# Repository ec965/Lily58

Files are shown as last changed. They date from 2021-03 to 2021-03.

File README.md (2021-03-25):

# SMD Lily58
* ATMEGA32U4 and STM32F072 variants
* Full SMD MCU and components.
* Original parts kept true to original placement where ever possible.
* Reversible PCB to reduce costs.
* USB C port on the left side.
* MCP23017 IO expander to reduce cost over two MCUs.

# Lily58
Lily58 is 6*4+4keys column-staggered split keyboard.
Lily58Lite-Pic

## [Document Site Here](https://kata0510.github.io/Lily58-Document/)

# Type

- Lily58 Pro
  - [PCB Data](https://github.com/kata0510/Lily58/tree/master/Pro/PCB)
  - [BuildGuide JP](https://kata0510.github.io/Lily58-Document/Lily58_Pro.html)
  - [BuildGuide EN](https://kata0510.github.io/Lily58-Document/Lily58_Pro_BG_ENG.html)
  - [Shop(Yushakobo)](https://yushakobo.jp/shop/lily58-pro/)
- Lily58 Lite Rev2
  - [BuildGuide(YouTube)](https://www.youtube.com/watch?v=t6HLQvqlsVM)
  - [BuildInfo](https://kata0510.github.io/Lily58-Document/Lily58_Lite_Rev2.html)
  - [Shop(BOOTH)](https://booth.pm/ja/items/1963895)
  - [Shop(Yushakobo)](https://yushakobo.jp/shop/consign_lily58-lite-rev2/)
- Lily58(Old)
  - [PCB Data](https://github.com/kata0510/Lily58/tree/master/pcb)
  - [BuildGuide](https://kata0510.github.io/Lily58-Document/Lily58_BG.html)
- Lily58 Lite Rev1(Old)
  - [PCB Data](https://github.com/kata0510/Lily58/tree/master/pcb)
  - [BuildGuide](https://kata0510.github.io/Lily58-Document/Lily58_Lite_BG.html)

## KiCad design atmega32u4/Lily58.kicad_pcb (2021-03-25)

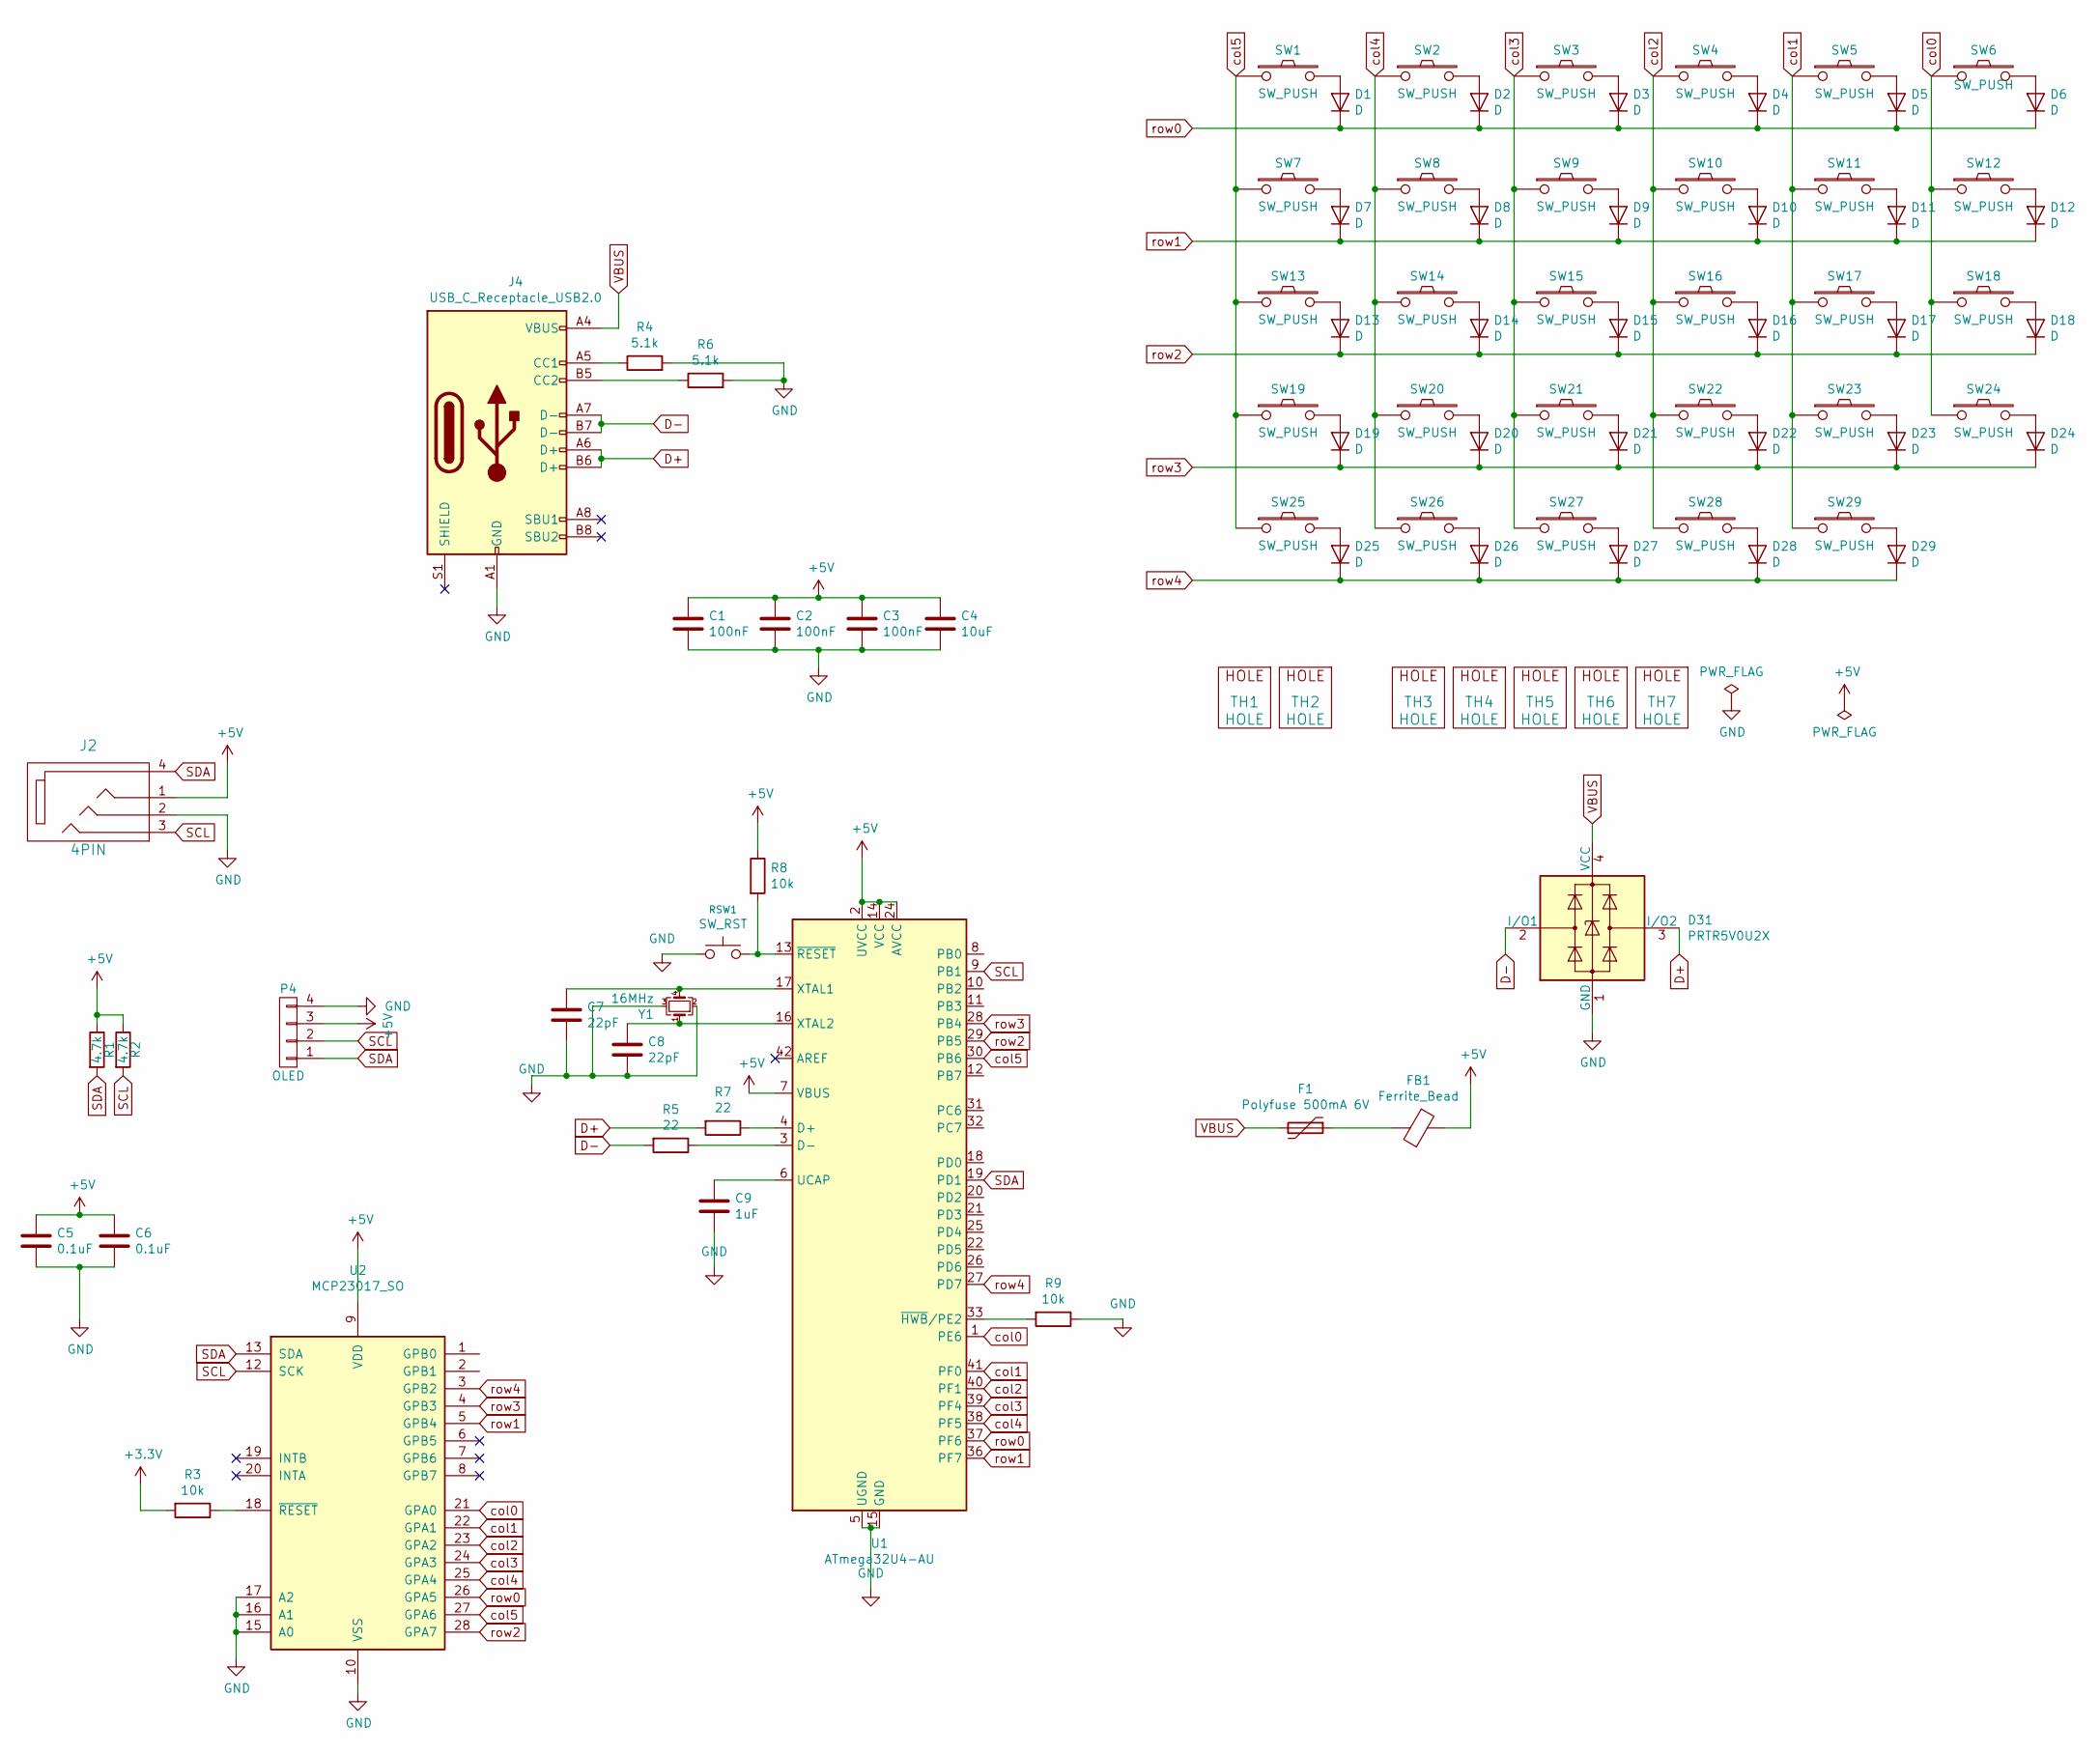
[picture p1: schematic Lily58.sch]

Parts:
C1, C2, C3: 100nF; C_0805_2012Metric
C4: 10uF; C_0805_2012Metric
C5, C6: 0.1uF; C_0805_2012Metric
C7, C8: 22pF; C_0805_2012Metric
C9: 1uF; C_0805_2012Metric
D1, D2, D3, D4, D5, D6, D7, D8, D9, D10, D11, D12, D13, D14, D15, D16, D17, D18, D19, D20, D21, D22, D23, D24, D25, D26, D27, D28, D29: D; Diode_TH_SOD123
D31: PRTR5V0U2X; SOT-143
F1: Polyfuse 500mA 6V; R_0805_2012Metric
FB1: Ferrite_Bead; L_0805_2012Metric
J2: 4PIN; MJ-4PP-9
J4: USB_C_Receptacle_USB2.0; USB_C_Receptacle_Palconn_UTC16-G
P4: OLED; MY_SIL-4
R1, R2: 4.7k; R_0805_2012Metric
R3, R8, R9: 10k; R_0805_2012Metric
R4, R6: 5.1k; R_0805_2012Metric
R5, R7: 22; R_0805_2012Metric
RSW1: SW_RST; TACT_SWITCH_TVBP06
SW1, SW2, SW3, SW4, SW5, SW6, SW7, SW8, SW9, SW10, SW11, SW12, SW13, SW14, SW15, SW16, SW17, SW18, SW19, SW20, SW21, SW22, SW23, SW24, SW25, SW27, SW28, SW29: SW_PUSH; MX_PG1350-Under_FLIP_HOLES_18mm
SW26: SW_PUSH; MX_PG1350-Under_FLIP_HOLES_27mm
TH1, TH2: HOLE; HOLE_M2
TH3, TH4, TH5, TH6, TH7: HOLE; HOLE_M2_TH
U1: ATmega32U4-AU; TQFP-44_10x10mm_P0.8mm
U2: MCP23017_SO; SOIC-28W_7.5x17.9mm_P1.27mm
Y1: 16MHz; Crystal_SMD_3225-4Pin_3.2x2.5mm

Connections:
D+: D31.3 (I/O2), J4.A6 (D+), J4.B6 (D+), R7.2
D-: D31.2 (I/O1), J4.A7 (D-), J4.B7 (D-), R5.2
GND: C1.2, C2.2, C3.2, C4.2, C5.2, C6.2, C7.2, C8.1, C9.2, D31.1 (GND), J2.2, J4.A1 (GND), J4.A12 (GND), J4.B1 (GND), J4.B12 (GND), P4.4, R4.2, R6.2, R9.1, RSW1.1, U1.5 (UGND), U1.15 (GND), U1.23 (GND), U1.35 (GND), U1.43 (GND), U2.10 (VSS), U2.15 (A0), U2.16 (A1), U2.17 (A2), Y1.2, Y1.3
unnamed: C7.1, U1.17 (XTAL1), Y1.4
unnamed: C8.2, U1.16 (XTAL2), Y1.1
unnamed: C9.1, U1.6 (UCAP)
unnamed: D1.2 (A), SW1.2
unnamed: D2.2 (A), SW2.2
unnamed: D3.2 (A), SW3.2
unnamed: D4.2 (A), SW4.2
unnamed: D5.2 (A), SW5.2
unnamed: D6.2 (A), SW6.2
unnamed: D7.2 (A), SW7.2
unnamed: D8.2 (A), SW8.2
unnamed: D9.2 (A), SW9.2
unnamed: D10.2 (A), SW10.2
unnamed: D11.2 (A), SW11.2
unnamed: D12.2 (A), SW12.2
unnamed: D13.2 (A), SW13.2
unnamed: D14.2 (A), SW14.2
unnamed: D15.2 (A), SW15.2
unnamed: D16.2 (A), SW16.2
unnamed: D17.2 (A), SW17.2
unnamed: D18.2 (A), SW18.2
unnamed: D19.2 (A), SW19.2
unnamed: D20.2 (A), SW20.2
unnamed: D21.2 (A), SW21.2
unnamed: D22.2 (A), SW22.2
unnamed: D23.2 (A), SW23.2
unnamed: D24.2 (A), SW24.2
unnamed: D25.2 (A), SW25.2
unnamed: D26.2 (A), SW26.2
unnamed: D27.2 (A), SW27.2
unnamed: D28.2 (A), SW28.2
unnamed: D29.2 (A), SW29.2
unnamed: F1.1, FB1.2
unnamed: J4.A5 (CC1), R4.1
unnamed: J4.B5 (CC2), R6.1
unnamed: R3.1, U2.18 (~RESET~)
unnamed: R5.1, U1.3 (D-)
unnamed: R7.1, U1.4 (D+)
unnamed: R8.2, RSW1.2, U1.13 (~RESET)
unnamed: R9.2, U1.33 (~HWB~/PE2)
SCL: J2.3, P4.2, R2.2, U1.9 (PB1), U2.12 (SCK)
SDA: J2.4, P4.1, R1.2, U1.19 (PD1), U2.13 (SDA)
VBUS: D31.4 (VCC), F1.2, J4.A4 (VBUS), J4.A9 (VBUS), J4.B4 (VBUS), J4.B9 (VBUS)
col0: SW6.1, SW12.1, SW18.1, SW24.1, U1.1 (PE6), U2.21 (GPA0)
col1: SW5.1, SW11.1, SW17.1, SW23.1, SW29.1, U1.41 (PF0), U2.22 (GPA1)
col2: SW4.1, SW10.1, SW16.1, SW22.1, SW28.1, U1.40 (PF1), U2.23 (GPA2)
col3: SW3.1, SW9.1, SW15.1, SW21.1, SW27.1, U1.39 (PF4), U2.24 (GPA3)
col4: SW2.1, SW8.1, SW14.1, SW20.1, SW26.1, U1.38 (PF5), U2.25 (GPA4)
col5: SW1.1, SW7.1, SW13.1, SW19.1, SW25.1, U1.30 (PB6), U2.27 (GPA6)
row0: D1.1 (K), D2.1 (K), D3.1 (K), D4.1 (K), D5.1 (K), D6.1 (K), U1.37 (PF6), U2.26 (GPA5)
row1: D7.1 (K), D8.1 (K), D9.1 (K), D10.1 (K), D11.1 (K), D12.1 (K), U1.36 (PF7), U2.5 (GPB4)
row2: D13.1 (K), D14.1 (K), D15.1 (K), D16.1 (K), D17.1 (K), D18.1 (K), U1.29 (PB5), U2.28 (GPA7)
row3: D19.1 (K), D20.1 (K), D21.1 (K), D22.1 (K), D23.1 (K), D24.1 (K), U1.28 (PB4), U2.4 (GPB3)
row4: D25.1 (K), D26.1 (K), D27.1 (K), D28.1 (K), D29.1 (K), U1.27 (PD7), U2.3 (GPB2)

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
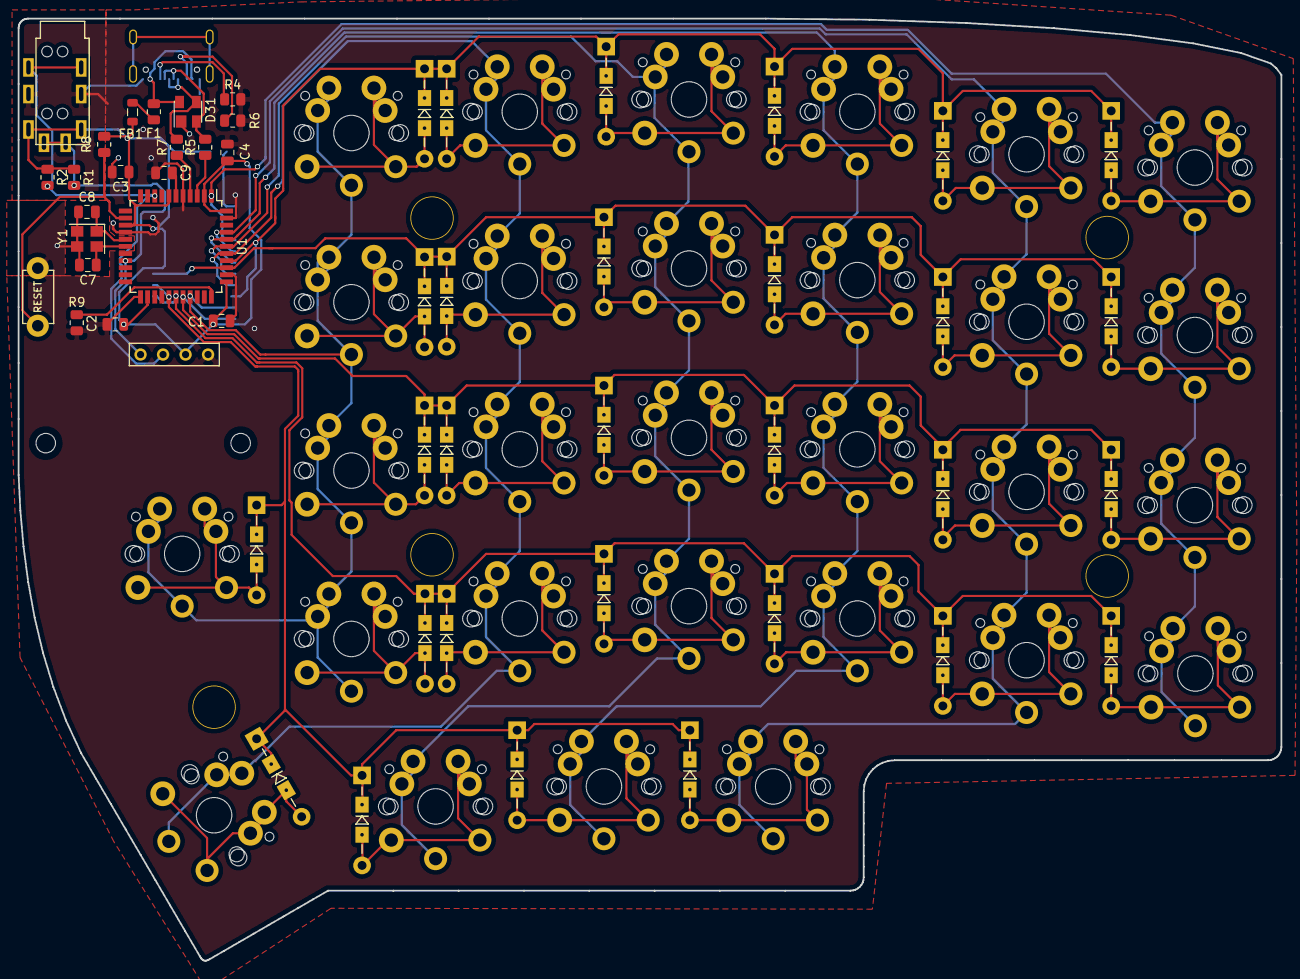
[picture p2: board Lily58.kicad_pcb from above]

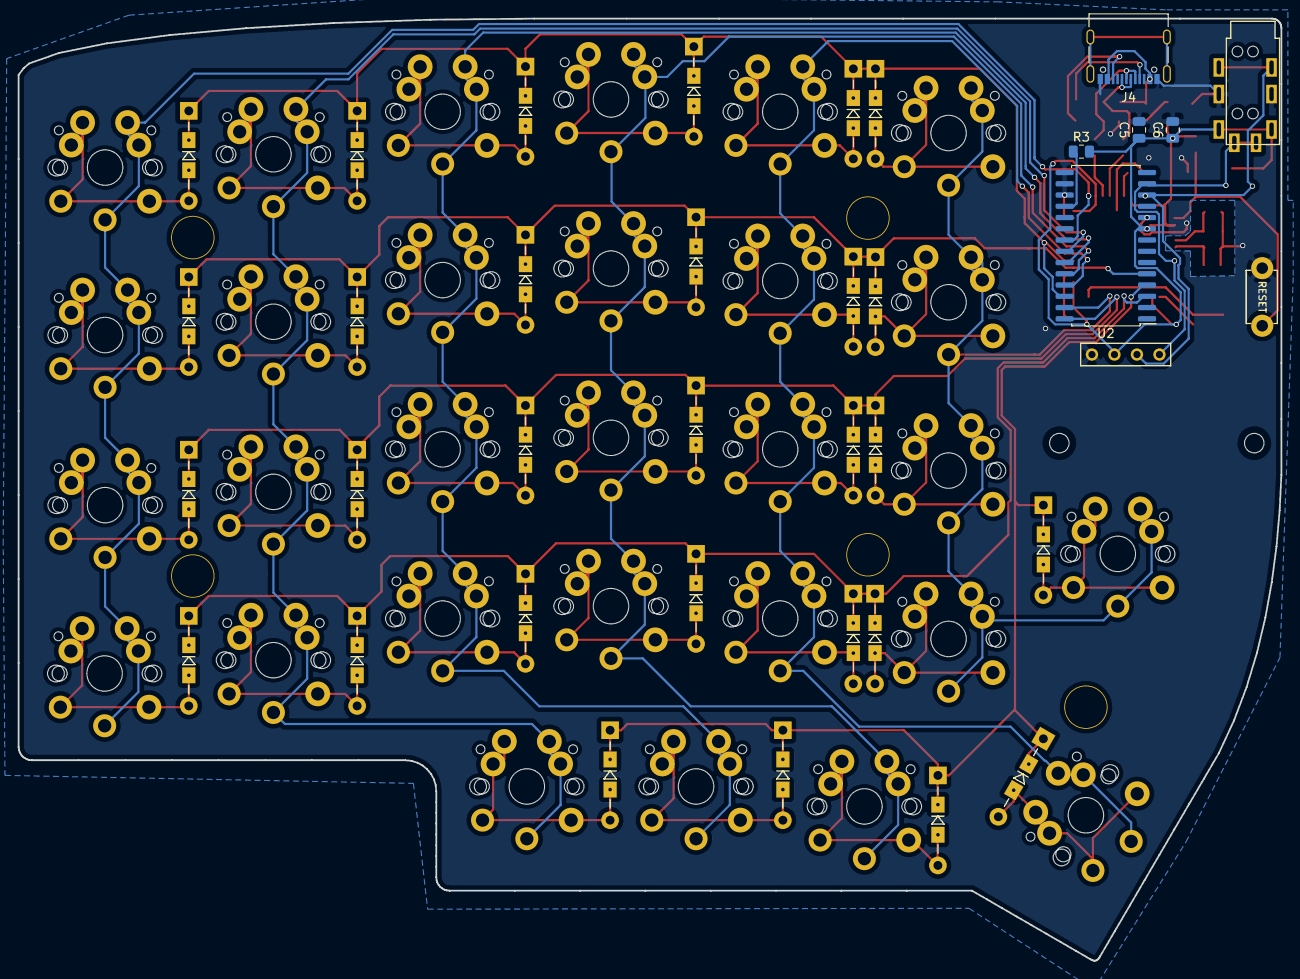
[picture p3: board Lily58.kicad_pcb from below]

Board: 2 copper layers, 142.5 x 106.3 mm, 93 parts (5 on the bottom side), 58 nets.

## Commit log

2021-03-24 setting up schematic and pcb
    [Lily58.kicad_pcb, Lily58.sch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]
2021-03-24 finishing pcb
    [Lily58.kicad_pcb, Lily58.sch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]
2021-03-25 adding atmega version
    [Lily58.kicad_pcb, Lily58.sch]
2021-03-25 removing ldo on atmega32u4
    [Lily58.kicad_pcb, Lily58.sch]
